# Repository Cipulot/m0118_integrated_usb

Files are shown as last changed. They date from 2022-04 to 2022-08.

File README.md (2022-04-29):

# m0118_integrated_usb

Drop-in replacement USB-C PCB for the Apple M0118 powered by QMK and VIAL.

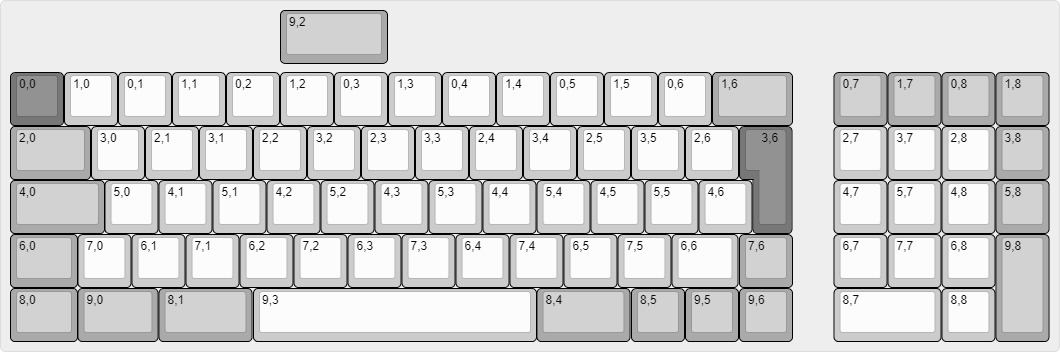
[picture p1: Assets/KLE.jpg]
KLE


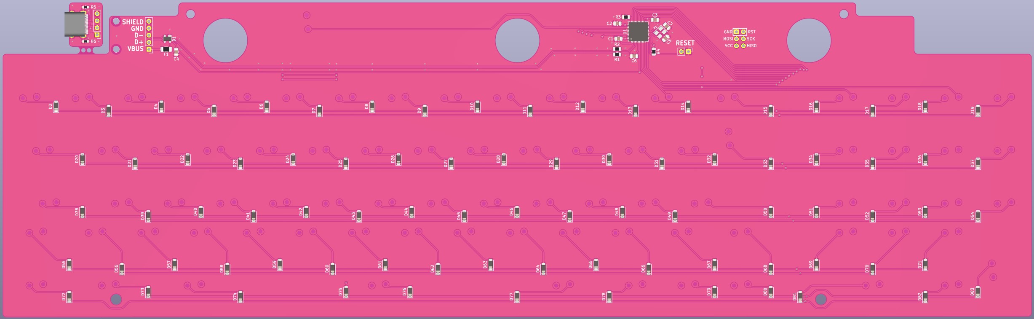
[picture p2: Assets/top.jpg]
Top PCB


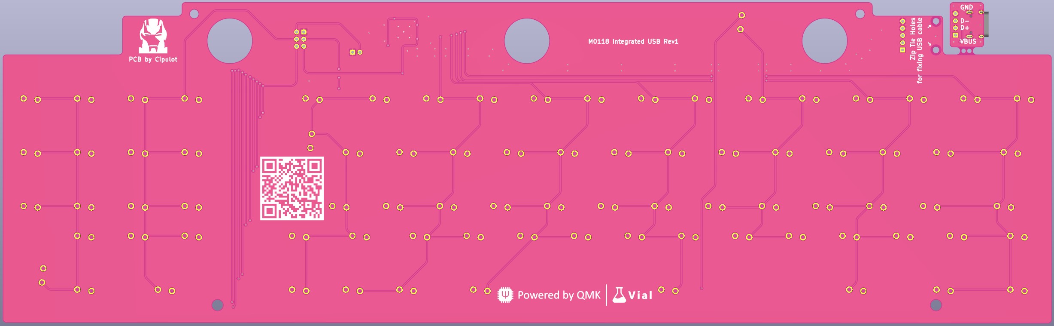
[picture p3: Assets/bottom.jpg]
Bottom PCB


## Daughterboard
The board comes with a snappable daughterboard with onboard USB-C. To avoid extra costs no connector is used. Instead the user will solder wires accordingly to the pin correspondence (marked on the PCB).

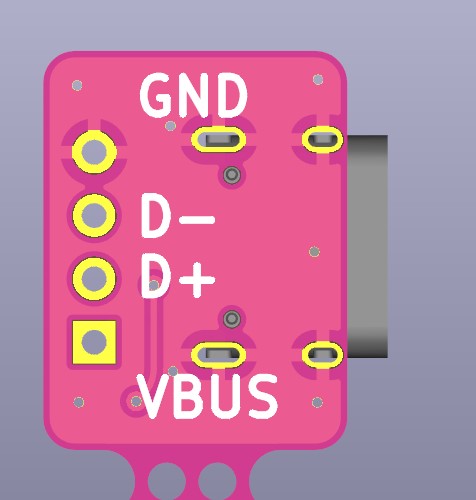
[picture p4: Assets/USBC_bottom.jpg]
USBC bottom PCB


## Internal Wire
Internal wiring of a USB cable is possible. For this reason 2 holes on the pcb are available to the user. You can use them to tie down the cable using a zip tie for added stability.

An extra pin is provided, the `Shiled` pin. This is electrically connected to the board GND and it's solely used to avoid clipping the shielding wire off from the cable (if present at all).

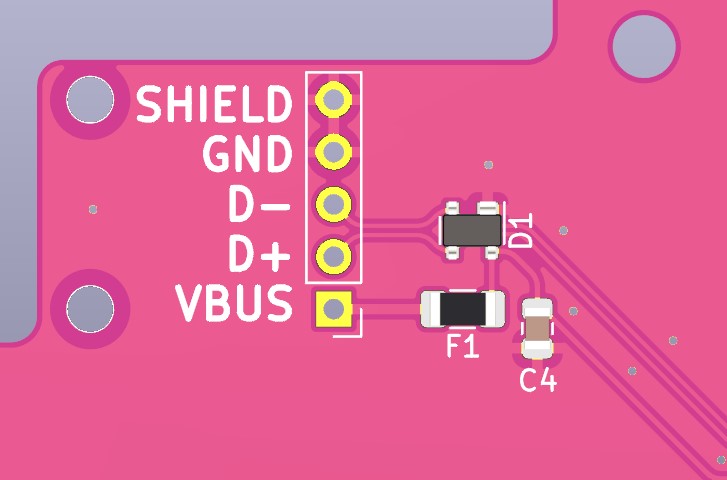
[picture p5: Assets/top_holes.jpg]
Top Holes


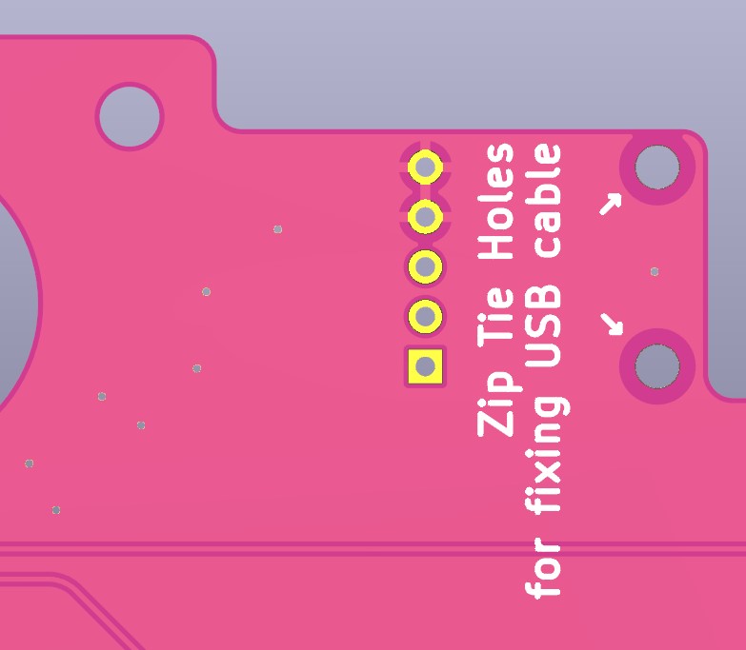
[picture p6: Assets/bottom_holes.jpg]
Bottom Holes


### hahahahaha funny QR

## Firmware

~~Firmware is in development. Keep an eye out on the commits for it.~~

Firmware is OUT!! Precompiled VIAL `.hex` file downloadable [here](https://github.com/Cipulot/m0118_integrated_usb/blob/main/Firmware/HEX/m0118_integrated_usb_vial.hex).

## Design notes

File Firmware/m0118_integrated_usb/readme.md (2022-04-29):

m0118_integrated_usb
===

Drop-in replacement USB-C PCB for the Apple M0118 powered by QMK and VIAL.

Keyboard Maintainer: [Cipulot](https://github.com/cipulot)

Hardware Supported: m0118_integrated_usb

Hardware Availability: [m0118_integrated_usb](https://github.com/cipulot/m0118_integrated_usb)

Make example for this keyboard (after setting up your build environment):

     make m0118_integrated_usb:vial

See the [build environment setup](https://docs.qmk.fm/#/getting_started_build_tools) and the [make instructions](https://docs.qmk.fm/#/getting_started_make_guide) for more information. Brand new to QMK? Start with our [Complete Newbs Guide](https://docs.qmk.fm/#/newbs).

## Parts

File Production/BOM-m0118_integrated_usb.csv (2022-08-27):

Comment | Designator | Package | Quantity | LCSC
D | D34,D60,D9,D57,D42,D65,D35,D21,D76,D10,D28,D56,D74,D58,D32,D61,D50,D17,D46,D48,D6,D52,D41,D38,D51,D7,D54,D19,D23,D63,D8,D69,D14,D33,D43,D78,D16,D55,D3,D22,D24,D44,D36,D82,D81,D15,D53,D75,D12,D68,D80,D49,D29,D67,D11,D77,D71,D79,D66,D70,D31,D25,D73,D62,D37,D13,D59,D18,D83,D26,D30,D5,D45,D72,D2,D47,D39,D4,D40,D27,D64,D20 | D_SOD-123 | 82 | C81598
22p | C7,C5 | C_0805_2012Metric | 2 | C1804
10k | R4,R3 | R_0805_2012Metric | 2 | C17414
22 | R2,R1 | R_0805_2012Metric | 2 | C17561
5.1k | R6,R5 | R_0603_1608Metric | 2 | C27834
16MHz | Y1 | Crystal_SMD_3225-4pin_3.2x2.5mm | 1 | C13738
500mA | F1 | Fuse_1206_3216Metric | 1 | C70076
ATmega32U4-M | U1 | QFN-44-1EP_7x7mm_P0.5mm_EP5.2x5.2mm | 1 | C112161
1u | C6 | C_0805_2012Metric | 1 | C28323
PRTR5V0U2X | D1 | SOT-143 | 1 | C2827688
0.1u | C1,C3,C2 | C_0805_2012Metric | 3 | C49678
10u | C4 | C_0805_2012Metric | 1 | C15850
HRO-TYPE-C-31-M-12 | USB1 | HRO-TYPE-C-31-M-12-Assembly | 1 | C165948

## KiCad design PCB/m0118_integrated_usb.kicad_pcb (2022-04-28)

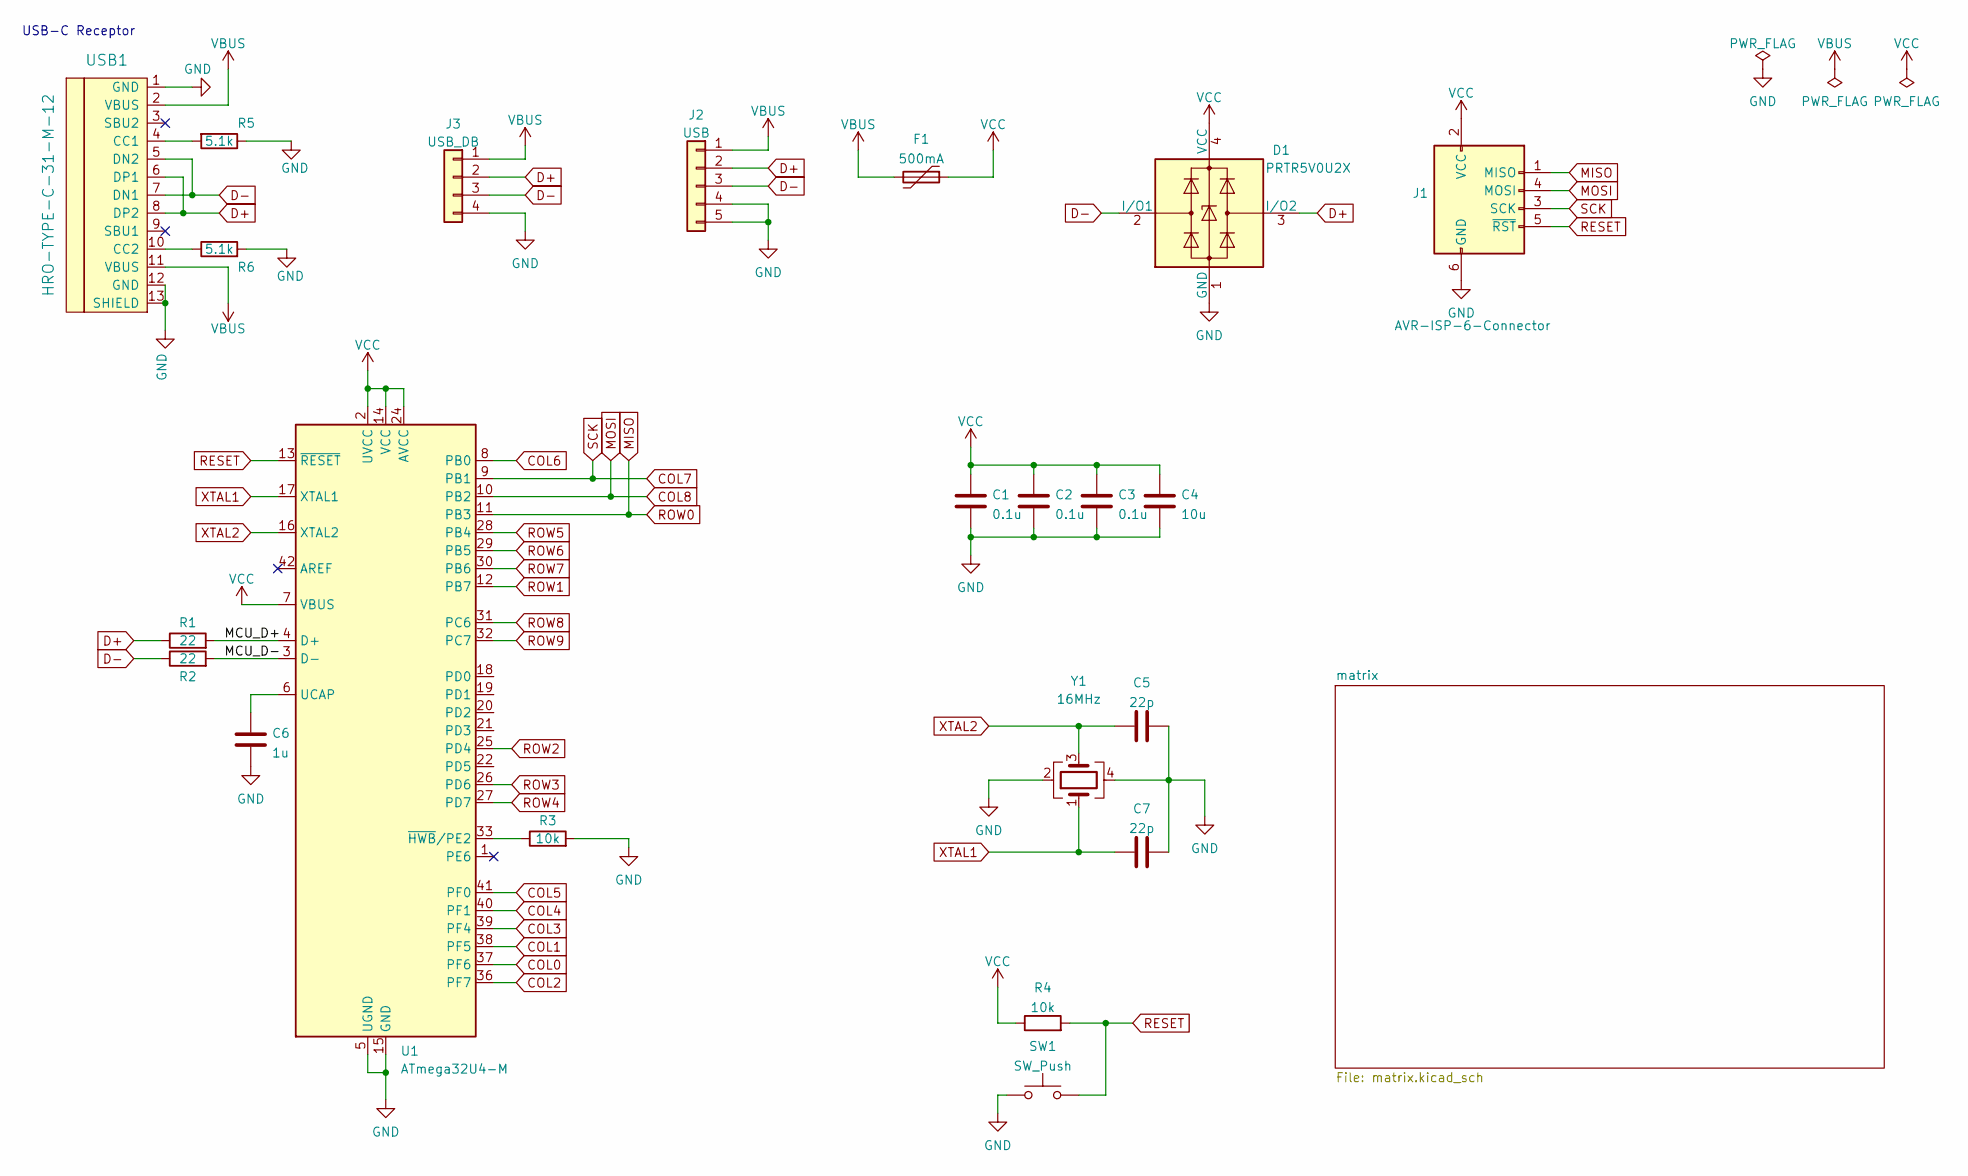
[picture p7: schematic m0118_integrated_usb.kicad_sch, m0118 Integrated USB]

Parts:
C1, C2, C3: 0.1u; C_0805_2012Metric
C4: 10u; C_0805_2012Metric
C5, C7: 22p; C_0805_2012Metric
C6: 1u; C_0805_2012Metric
D1: PRTR5V0U2X; SOT-143
F1: 500mA; Fuse_1206_3216Metric
J1: AVR-ISP-6-Connector; Reset_Pretty
J2: USB; PinHeader_1x05_P2.54mm_Vertical
J3: USB_DB; PinHeader_1x04_P2.54mm_Vertical
R1, R2: 22; R_0805_2012Metric
R3, R4: 10k; R_0805_2012Metric
R5, R6: 5.1k; R_0603_1608Metric
SW1: SW_Push; PinHeader_1x02_P2.54mm_Vertical
U1: ATmega32U4-M; QFN-44-1EP_7x7mm_P0.5mm_EP5.2x5.2mm
USB1: HRO-TYPE-C-31-M-12; HRO-TYPE-C-31-M-12-Assembly
Y1: 16MHz; Crystal_SMD_3225-4pin_3.2x2.5mm

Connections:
/MCU_D+: R1.2, U1.4 (D+)
/MCU_D-: R2.2, U1.3 (D-)
COL0: U1.37 (PF6); also elsewhere on the board
COL1: U1.38 (PF5); also elsewhere on the board
COL2: U1.36 (PF7); also elsewhere on the board
COL3: U1.39 (PF4); also elsewhere on the board
COL4: U1.40 (PF1); also elsewhere on the board
COL5: U1.41 (PF0); also elsewhere on the board
COL6: U1.8 (PB0); also elsewhere on the board
COL7: J1.3 (SCK), U1.9 (PB1); also elsewhere on the board
COL8: J1.4 (MOSI), U1.10 (PB2); also elsewhere on the board
D+: D1.3 (I/O2), J2.2, J3.2, R1.1, USB1.6 (DP1), USB1.8 (DP2)
D-: D1.2 (I/O1), J2.3, J3.3, R2.1, USB1.5 (DN2), USB1.7 (DN1)
GND: C1.2, C2.2, C3.2, C4.2, C5.1, C6.2, C7.1, D1.1 (GND), J1.6 (GND), J2.4, J2.5, J3.4, R3.2, R5.1, R6.2, SW1.1, U1.5 (UGND), U1.15 (GND), U1.23 (GND), U1.35 (GND), U1.43 (GND), U1.45 (GND), USB1.1 (GND), USB1.12 (GND), USB1.13 (SHIELD), Y1.2, Y1.4
MISO: J1.1 (MISO), U1.11 (PB3); also elsewhere on the board
unnamed: C6.1, U1.6 (UCAP)
unnamed: R3.1, U1.33 (~HWB/PE2)
unnamed: R5.2, USB1.4 (CC1)
unnamed: R6.1, USB1.10 (CC2)
RESET: J1.5 (~RST), R4.2, SW1.2, U1.13 (~RESET)
ROW1: U1.12 (PB7); also elsewhere on the board
ROW2: U1.25 (PD4); also elsewhere on the board
ROW3: U1.26 (PD6); also elsewhere on the board
ROW4: U1.27 (PD7); also elsewhere on the board
ROW5: U1.28 (PB4); also elsewhere on the board
ROW6: U1.29 (PB5); also elsewhere on the board
ROW7: U1.30 (PB6); also elsewhere on the board
ROW8: U1.31 (PC6); also elsewhere on the board
ROW9: U1.32 (PC7); also elsewhere on the board
VBUS: F1.2, J2.1, J3.1, USB1.2 (VBUS), USB1.11 (VBUS)
VCC: C1.1, C2.1, C3.1, C4.1, D1.4 (VCC), F1.1, J1.2 (VCC), R4.1, U1.2 (UVCC), U1.7 (VBUS), U1.14 (VCC), U1.24 (AVCC), U1.34 (VCC), U1.44 (AVCC)
XTAL1: C7.2, U1.17 (XTAL1), Y1.1
XTAL2: C5.2, U1.16 (XTAL2), Y1.3

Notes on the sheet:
USB-C Receptor

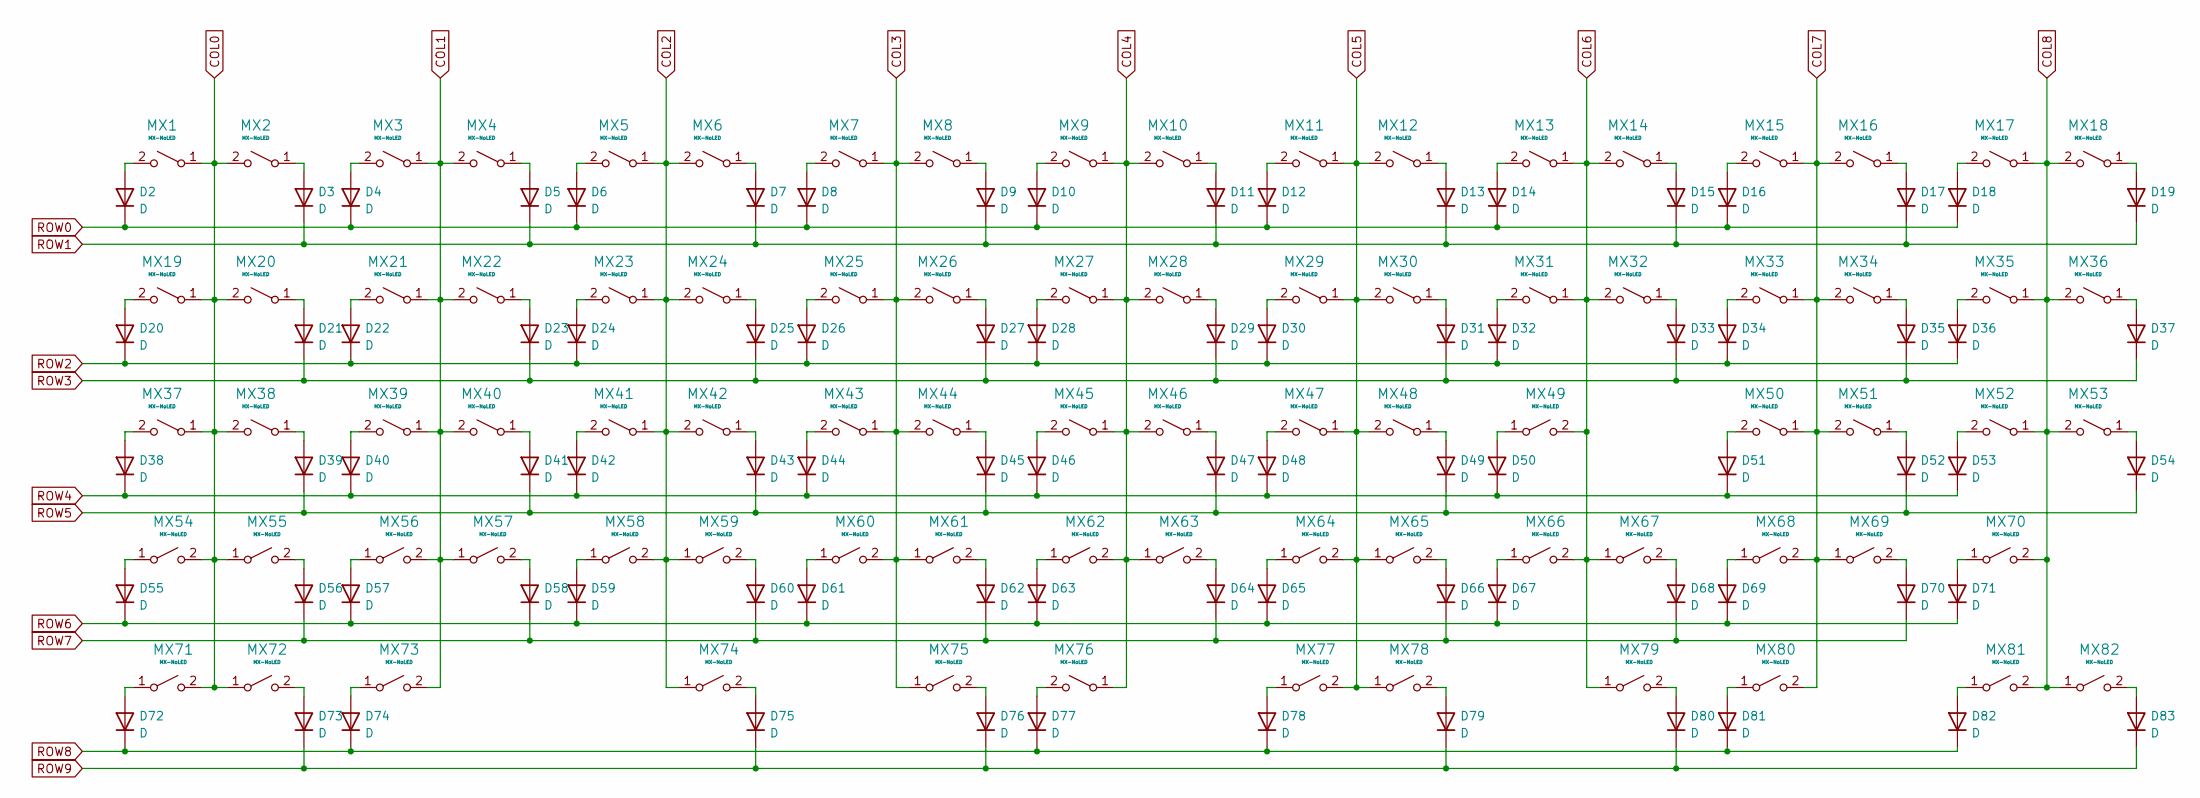
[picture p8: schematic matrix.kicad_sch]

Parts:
D2, D3, D4, D5, D6, D7, D8, D9, D10, D11, D12, D13, D14, D15, D16, D17, D18, D19, D20, D21, D22, D23, D24, D25, D26, D27, D28, D29, D30, D31, D32, D33, D34, D35, D36, D37, D38, D39, D40, D41, D42, D43, D44, D45, D46, D47, D48, D49, D50, D51, D52, D53, D54, D55, D56, D57, D58, D59, D60, D61, D62, D63, D64, D65, D66, D67, D68, D69, D70, D71, D72, D73, D74, D75, D76, D77, D78, D79, D80, D81, D82, D83: D; D_SOD-123
MX1, MX2, MX3, MX4, MX5, MX6, MX7, MX8, MX9, MX10, MX11, MX12, MX13, MX15, MX16, MX17, MX18, MX20, MX21, MX22, MX23, MX24, MX25, MX26, MX27, MX28, MX29, MX30, MX31, MX33, MX34, MX35, MX36, MX38, MX39, MX40, MX41, MX42, MX43, MX44, MX45, MX46, MX47, MX48, MX49, MX50, MX51, MX52, MX53, MX55, MX56, MX57, MX58, MX59, MX60, MX61, MX62, MX63, MX64, MX65, MX67, MX68, MX69, MX70, MX74, MX77, MX78, MX79, MX81: MX-NoLED; ALPS-1U
MX14, MX19, MX72: MX-NoLED; ALPS-1.5U
MX32: MX-NoLED; ALPS-SMALL-ISO
MX37, MX73, MX76: MX-NoLED; ALPS-1.75U
MX54, MX66, MX71: MX-NoLED; ALPS-1.25U
MX75: MX-NoLED; ALPS-5.25U
MX80, MX82: MX-NoLED; ALPS-2U

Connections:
COL0: MX1.1 (A), MX2.2 (B), MX19.1 (A), MX20.2 (B), MX37.1 (A), MX38.2 (B), MX54.2 (B), MX55.1 (A), MX71.2 (B), MX72.1 (A); also elsewhere on the board
COL1: MX3.1 (A), MX4.2 (B), MX21.1 (A), MX22.2 (B), MX39.1 (A), MX40.2 (B), MX56.2 (B), MX57.1 (A), MX73.2 (B); also elsewhere on the board
COL2: MX5.1 (A), MX6.2 (B), MX23.1 (A), MX24.2 (B), MX41.1 (A), MX42.2 (B), MX58.2 (B), MX59.1 (A), MX74.1 (A); also elsewhere on the board
COL3: MX7.1 (A), MX8.2 (B), MX25.1 (A), MX26.2 (B), MX43.1 (A), MX44.2 (B), MX60.2 (B), MX61.1 (A), MX75.1 (A); also elsewhere on the board
COL4: MX9.1 (A), MX10.2 (B), MX27.1 (A), MX28.2 (B), MX45.1 (A), MX46.2 (B), MX62.2 (B), MX63.1 (A), MX76.1 (A); also elsewhere on the board
COL5: MX11.1 (A), MX12.2 (B), MX29.1 (A), MX30.2 (B), MX47.1 (A), MX48.2 (B), MX64.2 (B), MX65.1 (A), MX77.2 (B), MX78.1 (A); also elsewhere on the board
COL6: MX13.1 (A), MX14.2 (B), MX31.1 (A), MX32.2 (B), MX49.2 (B), MX66.2 (B), MX67.1 (A), MX79.1 (A); also elsewhere on the board
COL7: MX15.1 (A), MX16.2 (B), MX33.1 (A), MX34.2 (B), MX50.1 (A), MX51.2 (B), MX68.2 (B), MX69.1 (A), MX80.2 (B); also elsewhere on the board
COL8: MX17.1 (A), MX18.2 (B), MX35.1 (A), MX36.2 (B), MX52.1 (A), MX53.2 (B), MX70.2 (B), MX81.2 (B), MX82.1 (A); also elsewhere on the board
MISO: D2.1 (K), D4.1 (K), D6.1 (K), D8.1 (K), D10.1 (K), D12.1 (K), D14.1 (K), D16.1 (K), D18.1 (K); also elsewhere on the board
unnamed: D2.2 (A), MX1.2 (B)
unnamed: D3.2 (A), MX2.1 (A)
unnamed: D4.2 (A), MX3.2 (B)
unnamed: D5.2 (A), MX4.1 (A)
unnamed: D6.2 (A), MX5.2 (B)
unnamed: D7.2 (A), MX6.1 (A)
unnamed: D8.2 (A), MX7.2 (B)
unnamed: D9.2 (A), MX8.1 (A)
unnamed: D10.2 (A), MX9.2 (B)
unnamed: D11.2 (A), MX10.1 (A)
unnamed: D12.2 (A), MX11.2 (B)
unnamed: D13.2 (A), MX12.1 (A)
unnamed: D14.2 (A), MX13.2 (B)
unnamed: D15.2 (A), MX14.1 (A)
unnamed: D16.2 (A), MX15.2 (B)
unnamed: D17.2 (A), MX16.1 (A)
unnamed: D18.2 (A), MX17.2 (B)
unnamed: D19.2 (A), MX18.1 (A)
unnamed: D20.2 (A), MX19.2 (B)
unnamed: D21.2 (A), MX20.1 (A)
unnamed: D22.2 (A), MX21.2 (B)
unnamed: D23.2 (A), MX22.1 (A)
unnamed: D24.2 (A), MX23.2 (B)
unnamed: D25.2 (A), MX24.1 (A)
unnamed: D26.2 (A), MX25.2 (B)
unnamed: D27.2 (A), MX26.1 (A)
unnamed: D28.2 (A), MX27.2 (B)
unnamed: D29.2 (A), MX28.1 (A)
unnamed: D30.2 (A), MX29.2 (B)
unnamed: D31.2 (A), MX30.1 (A)
unnamed: D32.2 (A), MX31.2 (B)
unnamed: D33.2 (A), MX32.1 (A)
unnamed: D34.2 (A), MX33.2 (B)
unnamed: D35.2 (A), MX34.1 (A)
unnamed: D36.2 (A), MX35.2 (B)
unnamed: D37.2 (A), MX36.1 (A)
unnamed: D38.2 (A), MX37.2 (B)
unnamed: D39.2 (A), MX38.1 (A)
unnamed: D40.2 (A), MX39.2 (B)
unnamed: D41.2 (A), MX40.1 (A)
unnamed: D42.2 (A), MX41.2 (B)
unnamed: D43.2 (A), MX42.1 (A)
unnamed: D44.2 (A), MX43.2 (B)
unnamed: D45.2 (A), MX44.1 (A)
unnamed: D46.2 (A), MX45.2 (B)
unnamed: D47.2 (A), MX46.1 (A)
unnamed: D48.2 (A), MX47.2 (B)
unnamed: D49.2 (A), MX48.1 (A)
unnamed: D50.2 (A), MX49.1 (A)
unnamed: D51.2 (A), MX50.2 (B)
unnamed: D52.2 (A), MX51.1 (A)
unnamed: D53.2 (A), MX52.2 (B)
unnamed: D54.2 (A), MX53.1 (A)
unnamed: D55.2 (A), MX54.1 (A)
unnamed: D56.2 (A), MX55.2 (B)
unnamed: D57.2 (A), MX56.1 (A)
unnamed: D58.2 (A), MX57.2 (B)
unnamed: D59.2 (A), MX58.1 (A)
unnamed: D60.2 (A), MX59.2 (B)
unnamed: D61.2 (A), MX60.1 (A)
unnamed: D62.2 (A), MX61.2 (B)
unnamed: D63.2 (A), MX62.1 (A)
unnamed: D64.2 (A), MX63.2 (B)
unnamed: D65.2 (A), MX64.1 (A)
unnamed: D66.2 (A), MX65.2 (B)
unnamed: D67.2 (A), MX66.1 (A)
unnamed: D68.2 (A), MX67.2 (B)
unnamed: D69.2 (A), MX68.1 (A)
unnamed: D70.2 (A), MX69.2 (B)
unnamed: D71.2 (A), MX70.1 (A)
unnamed: D72.2 (A), MX71.1 (A)
unnamed: D73.2 (A), MX72.2 (B)
unnamed: D74.2 (A), MX73.1 (A)
unnamed: D75.2 (A), MX74.2 (B)
unnamed: D76.2 (A), MX75.2 (B)
unnamed: D77.2 (A), MX76.2 (B)
unnamed: D78.2 (A), MX77.1 (A)
unnamed: D79.2 (A), MX78.2 (B)
unnamed: D80.2 (A), MX79.2 (B)
unnamed: D81.2 (A), MX80.1 (A)
unnamed: D82.2 (A), MX81.1 (A)
unnamed: D83.2 (A), MX82.2 (B)
ROW1: D3.1 (K), D5.1 (K), D7.1 (K), D9.1 (K), D11.1 (K), D13.1 (K), D15.1 (K), D17.1 (K), D19.1 (K); also elsewhere on the board
ROW2: D20.1 (K), D22.1 (K), D24.1 (K), D26.1 (K), D28.1 (K), D30.1 (K), D32.1 (K), D34.1 (K), D36.1 (K); also elsewhere on the board
ROW3: D21.1 (K), D23.1 (K), D25.1 (K), D27.1 (K), D29.1 (K), D31.1 (K), D33.1 (K), D35.1 (K), D37.1 (K); also elsewhere on the board
ROW4: D38.1 (K), D40.1 (K), D42.1 (K), D44.1 (K), D46.1 (K), D48.1 (K), D50.1 (K), D51.1 (K), D53.1 (K); also elsewhere on the board
ROW5: D39.1 (K), D41.1 (K), D43.1 (K), D45.1 (K), D47.1 (K), D49.1 (K), D52.1 (K), D54.1 (K); also elsewhere on the board
ROW6: D55.1 (K), D57.1 (K), D59.1 (K), D61.1 (K), D63.1 (K), D65.1 (K), D67.1 (K), D69.1 (K), D71.1 (K); also elsewhere on the board
ROW7: D56.1 (K), D58.1 (K), D60.1 (K), D62.1 (K), D64.1 (K), D66.1 (K), D68.1 (K), D70.1 (K); also elsewhere on the board
ROW8: D72.1 (K), D74.1 (K), D77.1 (K), D78.1 (K), D81.1 (K), D82.1 (K); also elsewhere on the board
ROW9: D73.1 (K), D75.1 (K), D76.1 (K), D79.1 (K), D80.1 (K), D83.1 (K); also elsewhere on the board

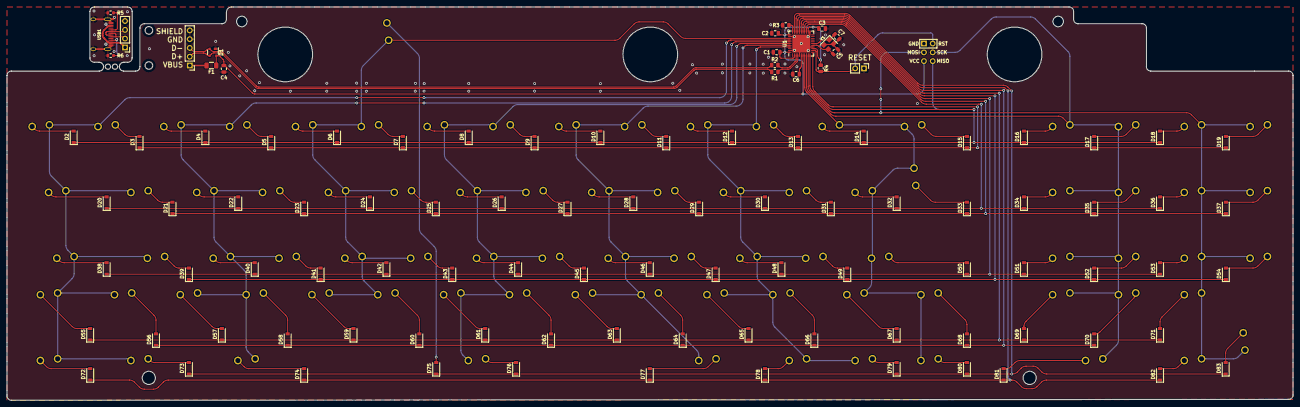
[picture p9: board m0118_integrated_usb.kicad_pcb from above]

Board: 2 copper layers, 372.1 x 113.8 mm, 188 parts (0 on the bottom side), 115 nets.

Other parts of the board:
H22, H22#2: MountingHole; HOLE_M2

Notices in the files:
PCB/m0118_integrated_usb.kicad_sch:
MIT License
